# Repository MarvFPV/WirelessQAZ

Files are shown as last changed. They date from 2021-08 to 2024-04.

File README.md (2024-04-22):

# WARNING: Unsure if i ever fixed the electrical issues around the charging IC, please sanity check before using

# QAZ-BLE

a 34 key, QAZ style, integrated BLE keyboard.   
Included are PCB files and 3d printable case files.

### PCB
The PCB includes in-switch LED lighting, USB-C, ESD protection and battery protection, enabling the user to install pretty much any Lipo cell that will fit inside the case

### Case
Hardware needed:

* 8x m3x10mm countersinks
* 4x m3x8mm button head

Printing:

* Print from any non-flexible material, i'd recommend to keep the bottom case metal free for RF reasons tho i have no clue how much of an effect that'd have real world
* no real layer height restrictions, make sure that you can print the threads at least decently well
* 4 or more shells are recommended for a better sounding keyboard aswell as stronger threads
* infill does not matter apart from sound

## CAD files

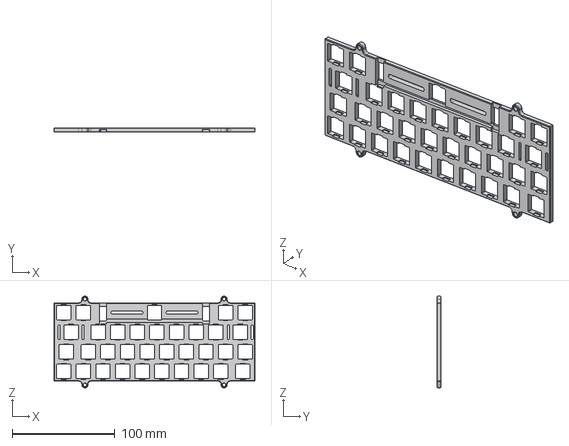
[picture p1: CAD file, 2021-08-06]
Case/STEP/Plate.step
195.3 x 4.00 x 89.2 mm

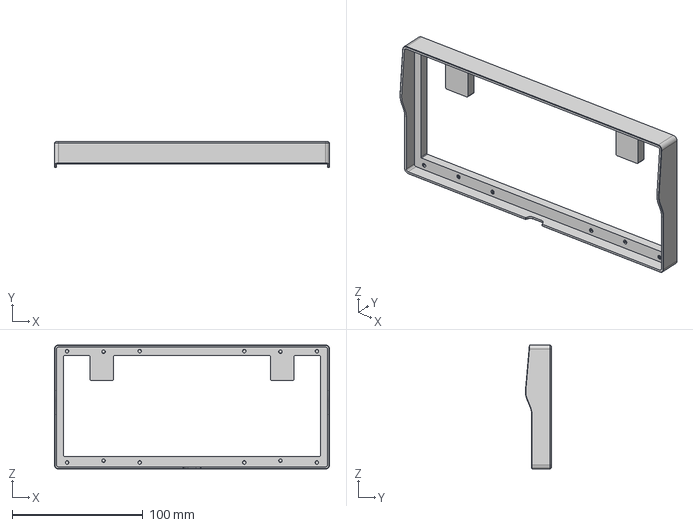
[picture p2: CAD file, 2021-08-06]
Case/STEP/TopWKL.step
210.3 x 20.1 x 94.7 mm

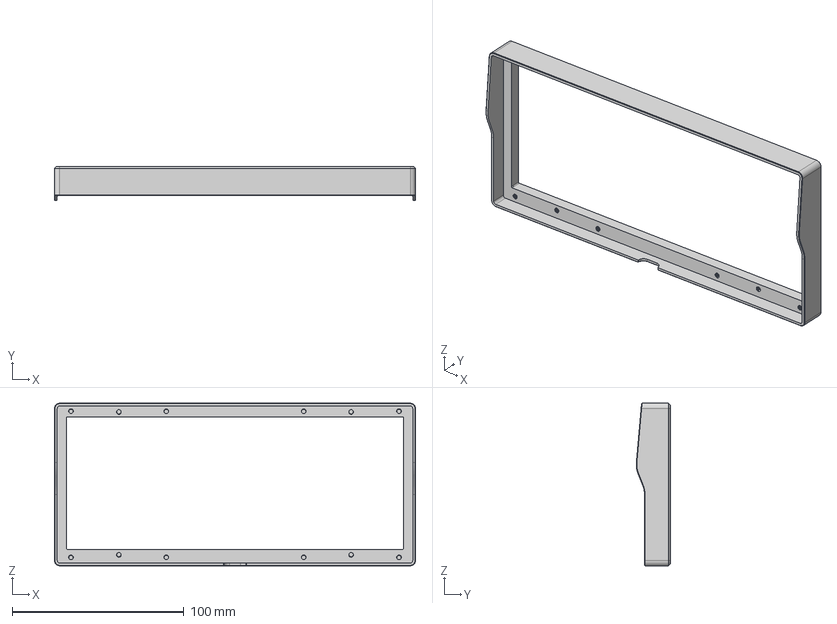
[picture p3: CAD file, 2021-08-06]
Case/STEP/Top.step
210.3 x 20.1 x 94.7 mm

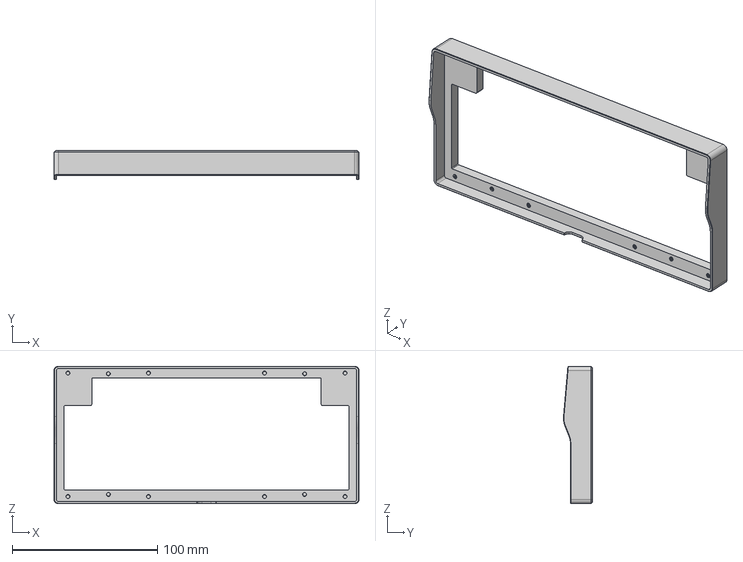
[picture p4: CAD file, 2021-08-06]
Case/STEP/TopHHKB.step
210.3 x 20.1 x 94.7 mm

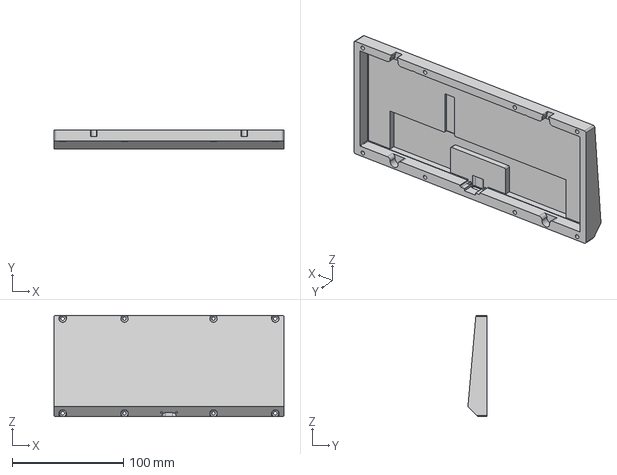
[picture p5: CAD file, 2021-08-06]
Case/STEP/Bottom.step
206.7 x 17.2 x 91.2 mm

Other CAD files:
Case/STL/Bottom.stl
Case/STL/Plate.stl
Case/STL/Top.stl
Case/STL/TopHHKB.stl
Case/STL/TopWKL.stl
Case/WirelessQAZ_CASE_MAIN v22.f3z

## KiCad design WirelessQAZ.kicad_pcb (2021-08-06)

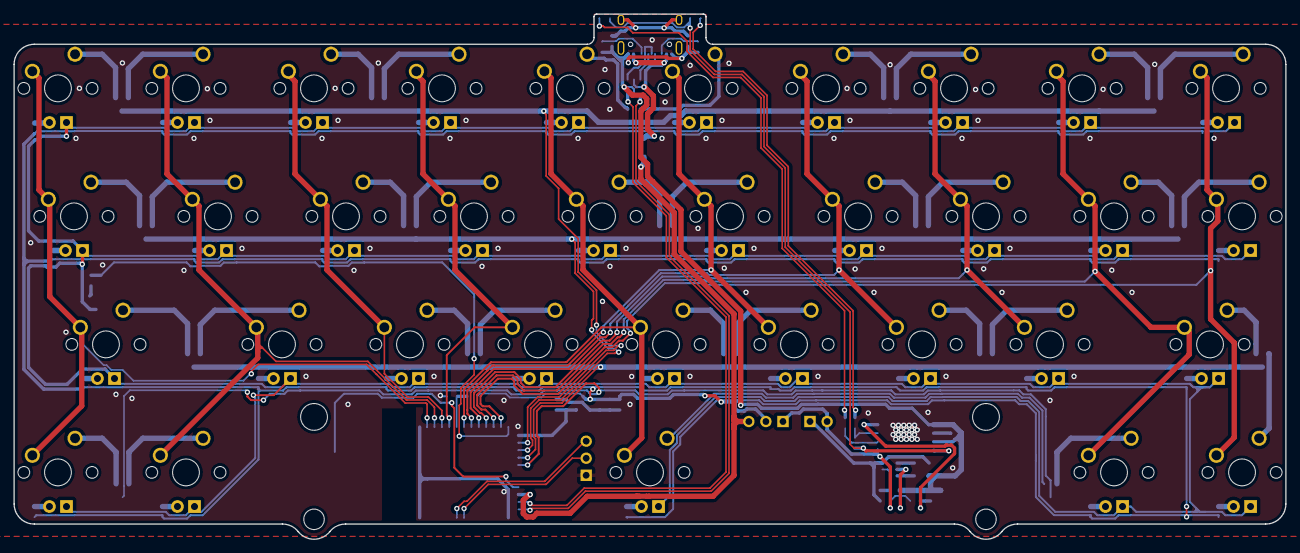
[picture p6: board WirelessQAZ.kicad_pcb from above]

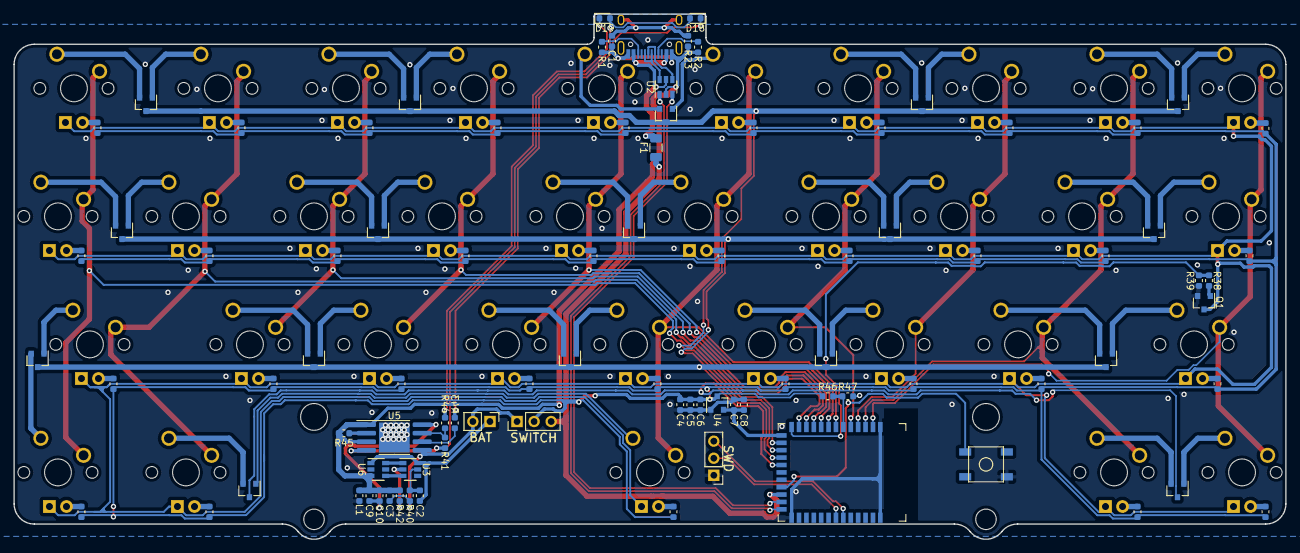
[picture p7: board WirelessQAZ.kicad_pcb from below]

Board: 2 copper layers, 189.3 x 78.1 mm, 124 parts (90 on the bottom side), 115 nets.

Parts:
BAT: BATT; PinHeader_1x02_P2.54mm_Vertical
C1, C2, C8, C10: 100nF; C_0603_1608Metric_stealth
C3, C9: 10uF; C_0603_1608Metric_stealth
C4, C5: 4.7uF; C_0603_1608Metric_stealth
C6, C7: 1uF; C_0603_1608Metric_stealth
D1, D2, D3, D4, D5, D6, D7, D8, D9, D10, D11, D12, D13, D14, D15, D16, D17: D_Schottky_x2_KCom_AAK; SOT-23
D18, D19: LED_Small; LED_0603_1608Metric
F1: 500mA; Fuse_1206_3216Metric
L1: PBY160808T-181Y-N; L_0603_1608Metric
MX1, MX2, MX3, MX4, MX5, MX6, MX7, MX8, MX9, MX12, MX13, MX14, MX15, MX16, MX17, MX18, MX19, MX20, MX22, MX23, MX24, MX25, MX26, MX27, MX28, MX30, MX31, MX33, MX34: MX-LED; MXOnly-1U
MX10, MX11: MX-LED; MXOnly-1.25U
MX21: MX-LED; MXOnly-1.75U
MX29: MX-LED; MXOnly-1.5U
MX32: MX-LED; MXOnly-6.25U-ReversedStabilizers
Q1: AO3400A; SOT-23
R1, R2: 5.1k; R_0603_1608Metric_stealth
R3, R4, R5, R6, R7, R8, R9, R10, R11, R12, R13, R14, R15, R16, R17, R18, R19, R20, R21, R22, R24, R25, R26, R27, R28, R29, R30, R31, R32, R33, R34, R35, R36, R37: 680; R_0603_1608Metric_stealth
R23: 1M; R_0603_1608Metric_stealth
R38, R40: 100; R_0603_1608Metric_stealth
R39, R41: 10k; R_0603_1608Metric_stealth
R42: 1k; R_0603_1608Metric_stealth
R43, R44: 2.7k; R_0603_1608Metric_stealth
R45: 1.8k; R_0603_1608Metric_stealth
R46: 1.3M; R_0603_1608Metric_stealth
R47: 2M; R_0603_1608Metric_stealth
SW1: SW_Push; SKQG-1155865
SWD: SWD; PinHeader_1x03_P2.54mm_Vertical
SWITCH: Switch; PinHeader_1x03_P2.54mm_Vertical
U1: nRF52840_holyiot_18010
U2: USBLC6-2SC6; SOT-23-6
U3: DW01A; SOT-23-6
U4: XC6206P332MR; SOT-23
U5: TP4056; SOP-8-1EP_4.57x4.57mm_P1.27mm_EP4.57x4.45mm
U6: FS8205; SOT-23-6
USB1: HRO-TYPE-C-31-M-12; HRO-TYPE-C-31-M-12-Assembly

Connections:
+3V3: C7.1, C8.1, U1.14, U4.2
+5V: C4.1, C5.1, C6.1, R3.2, R4.2, R5.2, R6.2, R7.2, R8.2, R9.2, R10.2, R11.2, R12.2, R13.2, R14.2, R15.2, R16.2, R17.2, R18.2, R19.2, R20.2, R21.2, R22.2, R24.2, R25.2, R26.2, R27.2, R28.2, R29.2, R30.2, R31.2, R32.2, R33.2, R34.2, R35.2, R36.2, R37.2, R46.1, SWITCH.2, U4.3
/5V_USB: F1.1, SWITCH.3, U1.22
/Col0: MX1.1, MX11.1, MX21.1, MX30.1, U1.2
/Col1: MX2.1, MX12.1, MX22.1, MX31.1, U1.3
/Col2: MX3.1, MX13.1, MX23.1, U1.4
/Col3: MX4.1, MX14.1, MX24.1, U1.5
/Col4: MX5.1, MX15.1, MX25.1, MX32.1, U1.7
/Col5: MX6.1, MX16.1, MX26.1, U1.8
/Col6: MX7.1, MX17.1, MX27.1, U1.9
/Col7: MX8.1, MX18.1, MX28.1, U1.10
/Col8: MX9.1, MX19.1, MX29.1, MX33.1, U1.11
/Col9: MX10.1, MX20.1, MX34.1, U1.12
/LED-: MX1.4, MX2.4, MX3.4, MX4.4, MX5.4, MX6.4, MX7.4, MX8.4, MX9.4, MX10.4, MX11.4, MX12.4, MX13.4, MX14.4, MX15.4, MX16.4, MX17.4, MX18.4, MX19.4, MX20.4, MX21.4, MX22.4, MX23.4, MX24.4, MX25.4, MX26.4, MX27.4, MX28.4, MX29.4, MX30.4, MX31.4, MX32.4, MX33.4, MX34.4, Q1.3
/LED_PWM: R38.2, R39.1, U1.13
/MCU_D+: U1.24, U2.1
/MCU_D-: U1.23, U2.3
/RESET: SW1.1, U1.21
/Row0: D1.3, D2.3, D3.3, D4.3, D5.3, U1.15
/Row1: D6.3, D7.3, D8.3, D9.3, D10.3, U1.16
/Row2: D11.3, D12.3, D13.3, D14.3, D15.3, U1.17
/Row3: D16.3, D17.3, U1.18
/USB_D+: U2.6, USB1.6, USB1.8
/USB_D-: U2.4, USB1.5, USB1.7
GND: C4.2, C5.2, C6.2, C7.2, C8.2, L1.1, Q1.2, R39.2, R47.2, SW1.2, SWD.1, U1.1, U1.25, U1.37, U4.1, U5.9
GNDPWR: C1.1, C3.2, C9.2, C10.2, L1.2, R1.1, R2.2, R23.2, R42.2, R45.2, U2.2, U5.1, U5.3, U6.3, USB1.1, USB1.12
unnamed: C1.2, R23.1, USB1.13
unnamed: BAT.1, C2.1, U3.6, U6.1
unnamed: C2.2, R40.1, U3.5
unnamed: BAT.2, C3.1, R40.2, SWITCH.1, U5.5
unnamed: C9.1, C10.1, U5.8
unnamed: D1.1, MX1.2
unnamed: D1.2, MX2.2
unnamed: D2.1, MX3.2
unnamed: D2.2, MX4.2
unnamed: D3.1, MX5.2
unnamed: D3.2, MX6.2
unnamed: D4.1, MX7.2
unnamed: D4.2, MX8.2
unnamed: D5.1, MX9.2
unnamed: D5.2, MX10.2
unnamed: D6.1, MX11.2
unnamed: D6.2, MX12.2
unnamed: D7.1, MX13.2
unnamed: D7.2, MX14.2
unnamed: D8.1, MX15.2
unnamed: D8.2, MX16.2
unnamed: D9.1, MX17.2
unnamed: D9.2, MX18.2
unnamed: D10.1, MX19.2
unnamed: D10.2, MX20.2
unnamed: D11.1, MX21.2
unnamed: D11.2, MX22.2
unnamed: D12.1, MX23.2
unnamed: D12.2, MX24.2
unnamed: D13.1, MX25.2
unnamed: D13.2, MX26.2
unnamed: D14.1, MX27.2
unnamed: D14.2, MX28.2
unnamed: D15.1, MX29.2
unnamed: D15.2, MX34.2
unnamed: D16.1, MX30.2
unnamed: D16.2, MX31.2
unnamed: D17.1, MX32.2
unnamed: D17.2, MX33.2
unnamed: D18.1, R43.1
unnamed: D18.2, D19.2, R41.1, U5.4
unnamed: D19.1, R44.1
unnamed: F1.2, U2.5, USB1.2, USB1.11
unnamed: SWD.2, U1.31
unnamed: SWD.3, U1.32
unnamed: MX1.3, R3.1
unnamed: MX2.3, R4.1
unnamed: MX3.3, R5.1
unnamed: MX4.3, R6.1
unnamed: MX5.3, R7.1
unnamed: MX6.3, R8.1
unnamed: MX7.3, R9.1
unnamed: MX8.3, R10.1
unnamed: MX9.3, R11.1
unnamed: MX10.3, R12.1
unnamed: MX11.3, R13.1
unnamed: MX12.3, R14.1
unnamed: MX13.3, R15.1
unnamed: MX14.3, R16.1
unnamed: MX15.3, R17.1
unnamed: MX16.3, R18.1
unnamed: MX17.3, R19.1
unnamed: MX18.3, R20.1
unnamed: MX19.3, R21.1
unnamed: MX20.3, R22.1
unnamed: MX21.3, R24.1
unnamed: MX22.3, R25.1
unnamed: MX23.3, R26.1
unnamed: MX24.3, R27.1
unnamed: MX25.3, R28.1
unnamed: MX26.3, R29.1
unnamed: MX27.3, R30.1
unnamed: MX28.3, R31.1
unnamed: MX29.3, R32.1
unnamed: MX30.3, R33.1
unnamed: MX31.3, R34.1
unnamed: MX32.3, R35.1
unnamed: MX33.3, R36.1
unnamed: MX34.3, R37.1
unnamed: Q1.1, R38.1
unnamed: R1.2, USB1.10
unnamed: R2.1, USB1.4
unnamed: R41.2, R44.2, U5.7
unnamed: R42.1, U3.2
unnamed: R43.2, U5.6
unnamed: R45.1, U5.2
unnamed: R46.2, R47.1, U1.6
unnamed: U3.1, U6.6
unnamed: U3.3, U6.4
